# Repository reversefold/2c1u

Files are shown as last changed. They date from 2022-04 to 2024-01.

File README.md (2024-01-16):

# 2c1u - Two computers, one USB port

The name is a riff on 2p1c, a shorthand for "Two players, one controller", a fun challenge that some speedrunners enjoy.

This project has software and hardware designs which form a USB switch, allowing for automatically moving a USB device between two computers, either through pressing of a hardware button or controlled via software running on the computers. If you plug a USB hub into the port that is switched you can switch, for instance, a keyboard and mouse between two computers, as if you were using software like Synergy.

## Layout
* 2c1u_kicad - KiCAD files for the hardware of the project, including a PCB layout.
* CircuitPy_Adafruit - Software for the Raspberry Pi devices that the hardware uses.
* 2c1u, pyproject.toml, pdm.lock - These constitute the computer software which communicate to the hardware over USB-Serial.

## Hardware
Required hardware:
* 2x [Adafruit Feather RP2040](https://www.adafruit.com/product/4884)
* 2x [TinkerBoy USB 2.0 Hub Breakout](https://www.tinkerboy.xyz/product/tinkerboy-usb-hub-4-port-usb-hub-2-0/)
* 3x [Adafruit 4090 - USB-C Breakout](https://www.adafruit.com/product/4090)
* 2x [Omron G6SK-2-DC5 relays](https://www.mouser.com/ProductDetail/Omron-Electronics/G6SK-2-DC5?qs=Mrnyg3lK62HQss%2FMQAyqbw%3D%3D)
* 2x [PN2222A Transistor](https://www.digikey.com/en/products/detail/nte-electronics-inc/PN2222A/11655004)
* 2x [Tactile Button Switch](https://www.adafruit.com/product/367)
* 1x [Sparkfun Cherry MX Switch Breakout](https://www.sparkfun.com/products/13773)
* 1x Cherry MX Compatible Switch
* 1x Keycap
* 2x 1K resistors
* 2x 10K resistors

I am also using several feather breakout boards for additional output as I had them around to play with:
* 1x [NeoPixel FeatherWing](https://www.adafruit.com/product/2945)
* 1x [Adafruit FeatherWing OLED - 128x64](https://www.adafruit.com/product/4650)
* 1x [FeatherWing Tripler Mini Kit](https://www.adafruit.com/product/3417)

You will additionally need PCB mount headers for the various components and either breadboards or a custom PCB (see fully functional PCB in `2c1u_kicad`). Note that the TinkerBoy USB 2.0 Hub Breakout boards are not breadboard compatible, the holes are not uniformly separated and require some creativity to hook up with a breadboard.

All of the soldering for the PCB are through-hole, as are nearly all of the boards. The one exception is the two data pads on the RP2040 boards. These pads connect to the 2 data pins of the USB connector so they can be used to wire up the RP2040 to the TinkerBoy boards as a USB device.

The Raspberry Pi boards are the brains of the switch. Each one connects to one of the computers as a USB serial device as a control channel. The primary one also controls the relays which switch the USB devices between the two computers.

One USB connector is for the input device to switch between the two hosts. I use a simple USB hub and plug both my keyboard and mouse into it, then plug the hub into the switch. The other 2 USB connectors connect to the two host computers. The TinkerBoy boards act as USB hubs, allowing both the RPi boards and the input devices to be connected via one USB connection. Note that this switch supports USB 2.0 only, so it's only really useful for lower bandwidth devices, like HID devices.

The Cherry MX switch allows switching between the two host computers manually. The two small switch buttons next to the USB connectors on the PCB can be held down while plugging in the associated USB cable to have the RPi start up in developer mode, with a repl usb-serial connection and as usb mass storage.

## Device-side software
The device-side software is written in Python for CircuitPy running on an Adafruit device. For the secondary create a file named `secondary` in the root of the drive.

The `boot.py` file turns on the data interface and turns off the repl interface, as well as turns off the ability of the CircuitPy device to be a USB drive. If you want access to the USB drive and repl interface you can pull pin D5 up (the buttons next to the USB connectors on the PCB are for this).

## Computer-side software
The computer-side software is written in Python and uses pdm for dependency management. Once you've installed pdm, change to the project directory, use the command `pdm install` to have pdm install all of the dependencies, then use the command `pdm run python 2c1u/main.py` to start the software. Until you have the right hardware hooked up it will loop with exceptions about not finding the serial interface.

The code near the top that defines `X_EDGE` configures how the edge of the screen is detected for the two machines, one Windows on the right, and one not Windows on the left.

## History

This project is the culmination of years of thinking and tinkering in my free time. For a long time, I have used projects such as x2vnc and Synergy to have the mouse and keyboard of one computer move to another computer's screen over the network, allowing for easy use of multiple computers with their own screens with a single keyboard and mouse. When I started working from home more often I wanted a way to switch between my personal and work computers seamlessly. Synergy did just that for me for a while but there were always caveats. Slowdown on the computers and random network errors would cause the input to lag or disconnect.

When my work computer was forced to have a full tunnel VPN the fully software-based network solution just wouldn't work reliably any more. The classic solution to this was a KVM, a hardware switch meant to move a keyboard, video, and mouse from one computer to another. I had no need for the video part of this, however, and I had trouble finding anything which could be software controlled. I wanted to mimic what I could do with Synergy, moving my mouse to one side of the monitor and have my mouse and keyboard move seamlessly to the other computer's monitor next to it.

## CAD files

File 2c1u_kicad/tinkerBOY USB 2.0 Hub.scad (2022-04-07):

board_width = 21.86; // mm
board_width_px = 755;
board_height = 14.02; // mm
board_height_px = 476;
width_px_per_mm = board_width_px / board_width;
height_px_per_mm = board_height_px / board_height;

echo(width_px_per_mm=width_px_per_mm, height_px_per_mm=height_px_per_mm);

pad_width_px = 64;
hole_width_px = 32;
pad_width = pad_width_px / width_px_per_mm;
hole_width = hole_width_px / width_px_per_mm;

echo(pad_width=pad_width, hole_width=hole_width);

left_to_center_of_first_pad_px = 47;
left_pad_x = left_to_center_of_first_pad_px / width_px_per_mm;
bottom_to_center_of_pad_px = 39;
pad_y = bottom_to_center_of_pad_px / width_px_per_mm;
echo(left_pad_x=left_pad_x);

pad_group_center_dist_px = 89;
pad_group_center_dist = pad_group_center_dist_px / width_px_per_mm;
echo(pad_group_center_dist=pad_group_center_dist);
pad_group_padding_px = 102;
pad_group_padding = pad_group_padding_px / width_px_per_mm;
echo(pad_group_padding=pad_group_padding);

$fn = 30;

echo(79 / width_px_per_mm);
echo(169 / width_px_per_mm);

difference() {
    square(size=[board_width, board_height]);

    for(i = [0 : 1 : 7]) {
        echo(i=i, pad_x=pad_x);
        pad_x = left_pad_x + floor(i / 2) * (pad_group_center_dist + pad_group_padding) + (i % 2) * pad_group_center_dist;
        translate([pad_x, pad_y, 0]) {
            cylinder(h=2, r=pad_width / 2, center=true);
        }
    }
}
/*
343.55 px / cm

hole width 36px = 0.10479 cm
pad width 64px = 1.8629 cm
dist from left to center 47px = 0.166 cm
bottom to center 39px = 0.163 cm

dist between first centers 89px = 0.259 cm

pad size 2.1121
hole size 1.0479

103px = 0.2998cm
*/

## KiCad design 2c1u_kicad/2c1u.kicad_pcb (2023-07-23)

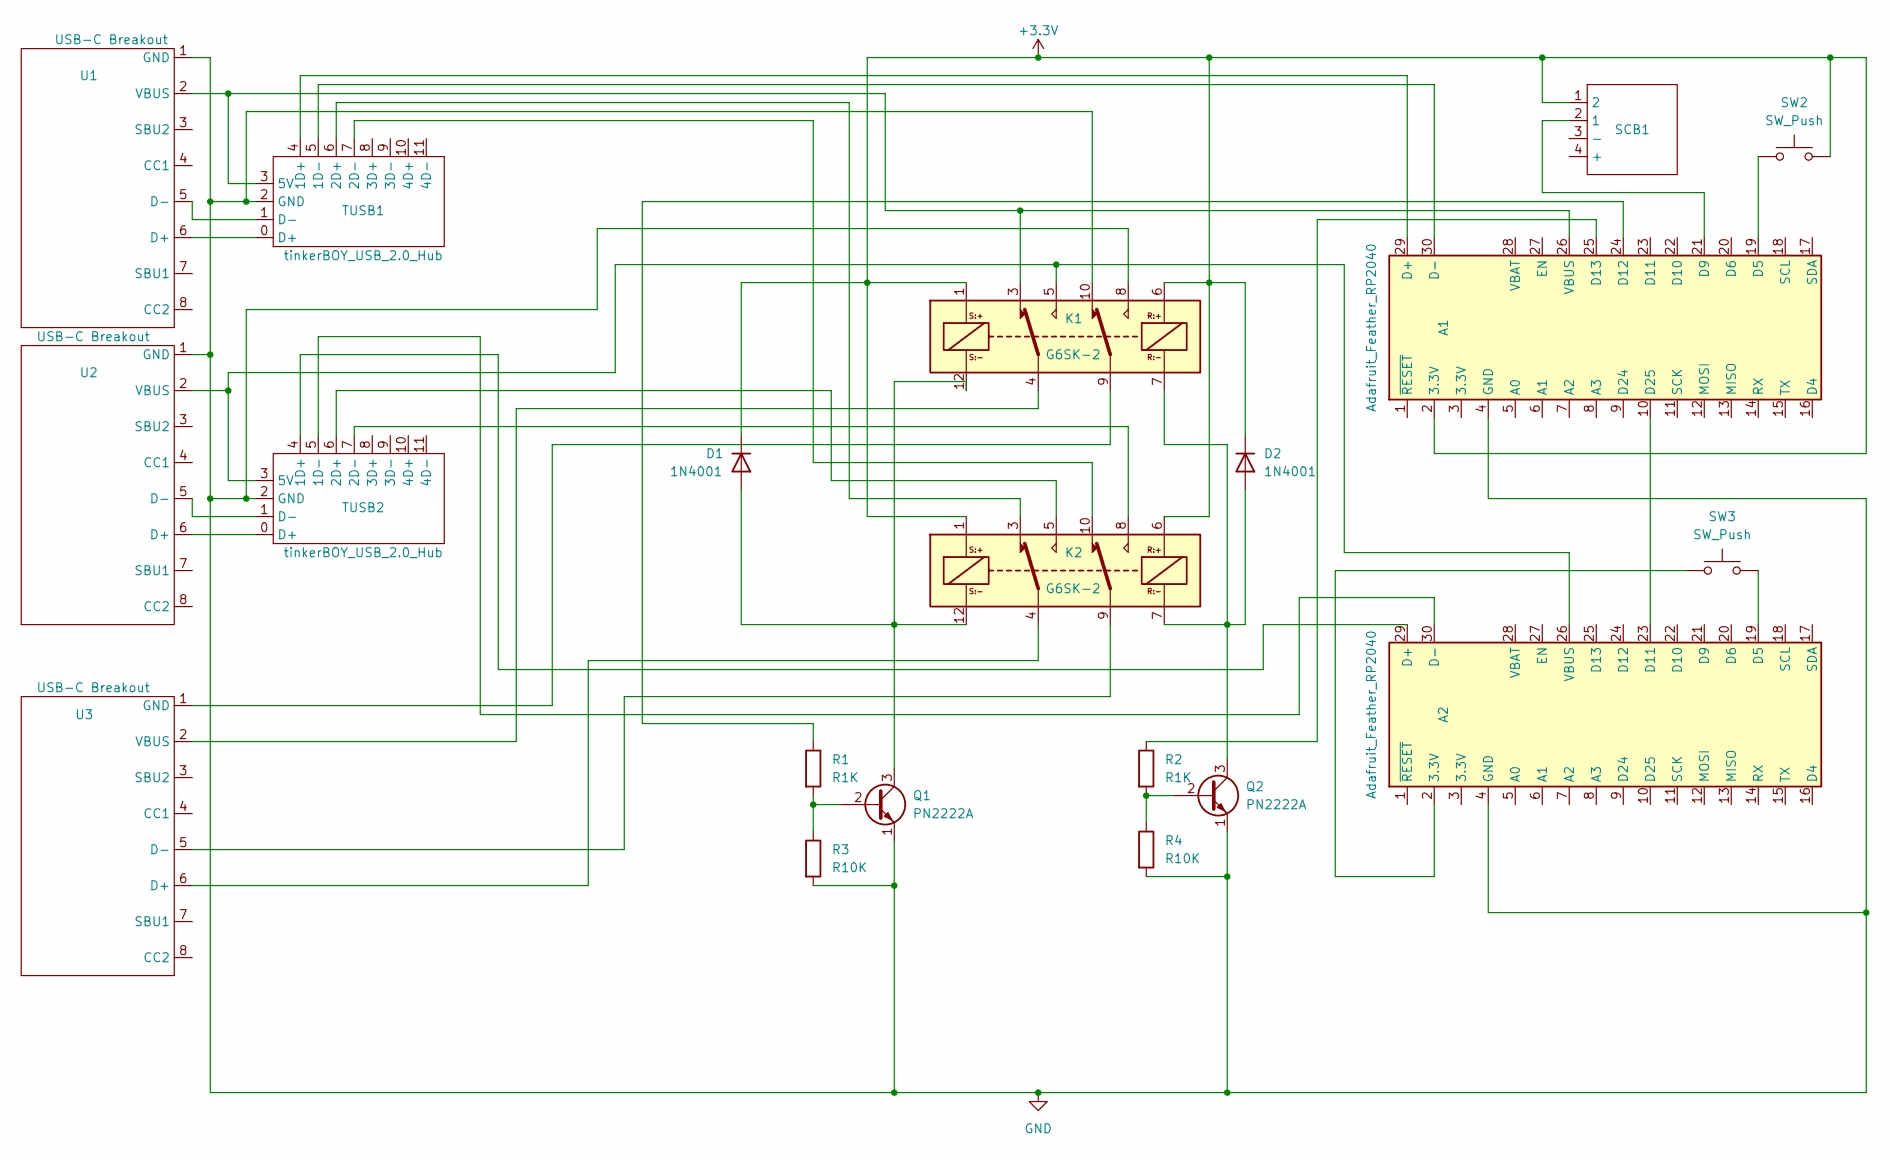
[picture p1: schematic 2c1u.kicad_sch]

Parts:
A1, A2: Adafruit_Feather_RP2040; Adafruit Feather RP2040
D1, D2: 1N4001; D_DO-41_SOD81_P10.16mm_Horizontal
K1, K2: G6SK-2; Relay_DPDT_Omron_G6SK-2
Q1, Q2: PN2222A; TO-92_Inline
R1, R2: R1K; R_Axial_DIN0204_L3.6mm_D1.6mm_P5.08mm_Horizontal
R3, R4: R10K; R_Axial_DIN0204_L3.6mm_D1.6mm_P5.08mm_Horizontal
SCB1: (no value)
SW2, SW3: SW_Push; SW_Tactile_Straight_KSL0Axx1LFTR
TUSB1, TUSB2: tinkerBOY_USB_2.0_Hub; tinkerBOY USB 2.0 Hub
U1, U2, U3: USB-C Breakout; Adafruit 4090 - USB-C Breakout

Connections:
+3V3: A1.2 (3.3V), D1.1 (K), D2.1 (K), K1.1, K1.6, K2.1, K2.6, SCB1.1 (2), SW2.2
GND: A1.4 (GND), A2.4 (GND), K1.8, K1.10, Q1.1 (E), Q2.1 (E), R3.2, R4.2, TUSB1.2 (GND), TUSB2.2 (GND), U1.1 (GND), U2.1 (GND)
unnamed: A1.10 (D25), A2.23 (D11)
unnamed: A1.19 (D5), SW2.1
unnamed: A1.24 (D12), R1.1
unnamed: A1.25 (D13), R2.1
unnamed: A1.26 (VBUS), K1.3, TUSB1.3 (5V), U1.2 (VBUS)
unnamed: A1.29 (D+), TUSB1.4 (1D+)
unnamed: A1.30 (D-), TUSB1.5 (1D-)
unnamed: A2.2 (3.3V), SW3.1
unnamed: A2.19 (D5), SW3.2
unnamed: A2.26 (VBUS), K1.5, TUSB2.3 (5V), U2.2 (VBUS)
unnamed: A2.29 (D+), TUSB2.4 (1D+)
unnamed: A2.30 (D-), TUSB2.5 (1D-)
unnamed: D1.2 (A), K1.12, K2.12, Q1.3 (C)
unnamed: D2.2 (A), K1.7, K2.7, Q2.3 (C)
unnamed: K1.4, U3.2 (VBUS)
unnamed: K1.9, U3.1 (GND)
unnamed: K2.3, TUSB1.6 (2D+)
unnamed: K2.4, U3.6 (D+)
unnamed: K2.5, TUSB2.6 (2D+)
unnamed: K2.8, TUSB2.7 (2D-)
unnamed: K2.9, U3.5 (D-)
unnamed: K2.10, TUSB1.7 (2D-)
unnamed: Q1.2 (B), R1.2, R3.1
unnamed: Q2.2 (B), R2.2, R4.1
unnamed: A1.21 (D9), SCB1.2 (1)
unnamed: TUSB1.0 (D+), U1.6 (D+)
unnamed: TUSB1.1 (D-), U1.5 (D-)
unnamed: TUSB2.0 (D+), U2.6 (D+)
unnamed: TUSB2.1 (D-), U2.5 (D-)

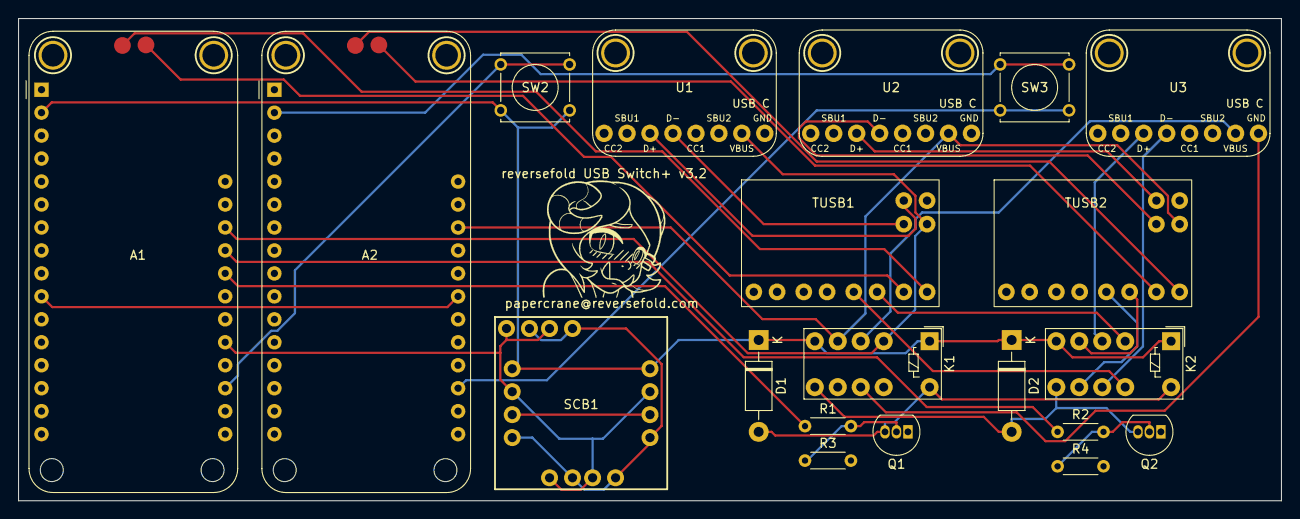
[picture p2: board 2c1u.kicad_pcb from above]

Board: 2 copper layers, 139.7 x 53.3 mm, 20 parts (0 on the bottom side), 31 nets.

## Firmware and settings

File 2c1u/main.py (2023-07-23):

import asyncio
import datetime
import glob
import logging
import sys

import adafruit_board_toolkit.circuitpython_serial
import serial_asyncio
import serial.serialutil
import pyautogui


logging.basicConfig(level=logging.INFO)
LOG = logging.getLogger(__name__)

zero_time_threshold = datetime.timedelta(seconds=0.2)
ser_write = None

loop = asyncio.new_event_loop()


class Operator(object):
    @staticmethod
    def apply(a, b):
        raise Unimplemented()


class GreaterThan(Operator):
    @staticmethod
    def apply(a, b):
        return a > b


class LessThan(Operator):
    @staticmethod
    def apply(a, b):
        return a < b


EDGE_THRESHOLD = 5
MAX_DIFF = 300
if sys.platform.startswith("win"):
    X_EDGE = 0 + EDGE_THRESHOLD
    OPERATOR = LessThan
else:
    X_EDGE = 2559 - EDGE_THRESHOLD
    OPERATOR = GreaterThan


ser_read = ser_write = None


async def serial_write():
    global ser_read, ser_write

    while True:
        while not ser_write:
            LOG.info("Waiting for serial write connection")
            await asyncio.sleep(1)

        try:
            command = b"hello\n\r"
            print(f"<<[{command}]")

            ser_write.write(command)  # write a string
            await ser_write.drain()
            print("written")

            # for _ in range(len(command)):
            #    a = await ser_read.read()  # Read the loopback chars and ignore
            # print("read echo")

            # reply = b""
            # while True:
            #     a = await ser_read.read(1)
            #     if a == b"\r":
            #         print(f">>[{reply}]")
            #         reply = b""
            #     else:
            #         reply += a
            #     await asyncio.sleep(0.1)
        except Exception:
            LOG.exception("Exception in serial_write loop, retrying in 1s")
            await asyncio.sleep(1)


async def open_serial():
    global ser_read, ser_write
    if ser_read:
        try:
            await ser_read.close()
        except Exception:
            LOG.exception("Exception closing serial read")
    if ser_write:
        try:
            await ser_write.close()
        except Exception:
            LOG.exception("Exception closing serial write")
    ports = adafruit_board_toolkit.circuitpython_serial.data_comports()
    if not ports:
        raise Exception("No adafruit board serial data connections found")
    serial_device = ports[0].device
    LOG.info("Connecting to serial device %s" % (serial_device,))
    ser_read, ser_write = await serial_asyncio.open_serial_connection(
        url=serial_device,
        baudrate=115200,
        loop=loop,
    )


async def serial_read():
    global ser_read, ser_write

    while True:
        # import ipdb; ipdb.set_trace()
        try:
            await open_serial()

            while not ser_read:
                LOG.info("Waiting for serial read connection")
                await asyncio.sleep(1)

            # command = b"hello\n\r"
            # print(f"<<[{command}]")

            # ser_write.write(command)  # write a string
            # await ser_write.drain()
            # print("written")

            # for _ in range(len(command)):
            #    a = await ser_read.read()  # Read the loopback chars and ignore
            # print("read echo")

            reply = b""
            while True:
                a = await ser_read.read(1)
                if a == b"\r":
                    print(f">>[{reply}]")
                    reply = b""
                else:
                    reply += a
                await asyncio.sleep(0.1)
        except Exception:
            LOG.exception("Exception in serial_read loop, retrying in 1s")
            await asyncio.sleep(1)
        finally:
            try:
                await ser_read.close()
            except Exception:
                LOG.exception("Exception closing serial read")
            try:
                await ser_write.close()
            except Exception:
                LOG.exception("Exception closing serial write")
            ser_read = ser_write = None


async def cursor_watch():
    while not ser_write:
        await asyncio.sleep(1)

    while True:
        try:
            last_pos_x = pyautogui.size()[0] / 2
            edge_start = None
            switched = False
            while True:
                await asyncio.sleep(0.1)
                pos_x, _ = pyautogui.position()
                if pos_x == last_pos_x and edge_start is None:
                    continue
                if pos_x != last_pos_x:
                    print(pos_x)
                diff = abs(last_pos_x - X_EDGE)
                if OPERATOR.apply(pos_x, X_EDGE) and (
                    edge_start is not None or diff < MAX_DIFF
                ):
                    if edge_start is None:
                        print(diff)
                        print("edge_start")
                        edge_start = datetime.datetime.now()
                    if datetime.datetime.now() - edge_start > zero_time_threshold:
                        if not switched:
                            print("switch")
                            switched = True
                            command = b"switch\n\r"
                            ser_write.write(command)
                            await ser_write.drain()
                            print(f"<<[{command}]")
                else:
                    edge_start = None
                    if switched:
                        print("Switch off")
                        switched = False
                last_pos_x = pos_x
        except serial.serialutil.SerialException:
            await open_serial()
        except Exception:
            LOG.exception("Exception in cursor_watch loop, retrying in 1s")
            await asyncio.sleep(0.1)


# loop.create_task(serial_write())
loop.create_task(serial_read())
loop.create_task(cursor_watch())
loop.run_forever()
loop.close()

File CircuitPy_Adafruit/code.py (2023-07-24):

import os
import time

import board
import digitalio
import neopixel
import supervisor
import usb_cdc


print("listening...")

RED = (255, 0, 0)
# YELLOW = (255, 150, 0)
# GREEN = (0, 255, 0)
# CYAN = (0, 255, 255)
BLUE = (0, 0, 255)
PURPLE = (180, 0, 255)
# WHITE = (255, 255, 255)
# OFF = (0, 0, 0)

try:
    os.stat("secondary")
    SECONDARY = True
    print("secondary")
except OSError:
    SECONDARY = False

PRIMARY = not SECONDARY


if PRIMARY:
    button = digitalio.DigitalInOut(board.D9)
    button.switch_to_input(pull=digitalio.Pull.DOWN)


if PRIMARY:
    pixels = neopixel.NeoPixel(board.D6, 8 * 4, brightness=0.05, auto_write=False)
    pixel = neopixel.NeoPixel(board.NEOPIXEL, 1, brightness=0.05, auto_write=False)
else:
    pixels = neopixel.NeoPixel(board.NEOPIXEL, 1, brightness=0.05, auto_write=False)

switch_to_0_out = digitalio.DigitalInOut(board.D13)
switch_to_0_out.switch_to_output()
switch_to_1_out = digitalio.DigitalInOut(board.D12)
switch_to_1_out.switch_to_output()

switch = digitalio.DigitalInOut(board.D4 if PRIMARY else board.D11)
switch.switch_to_output()

switch_in = digitalio.DigitalInOut(board.D25)
switch_in.switch_to_input(pull=digitalio.Pull.DOWN)

# output_enable = digitalio.DigitalInOut(board.A2)
# output_enable.switch_to_output()


if PRIMARY:
    try:
        import adafruit_displayio_sh1107

        # import adafruit_displayio_ssd1306
        import adafruit_display_text.label
        import displayio
        import terminalio

        displayio.release_displays()
        i2c = board.I2C()
        display_bus = displayio.I2CDisplay(i2c, device_address=0x3C)
        # display = adafruit_displayio_ssd1306.SSD1306(display_bus, width=128, height=32)
        display = adafruit_displayio_sh1107.SH1107(display_bus, width=128, height=64)
    except RuntimeError as exc:
        print("Error initializing display: %r" % (exc,))
        display = None


def update_display(text):
    if not display:
        return
    # Make the display context
    splash = displayio.Group()
    display.show(splash)

    color_bitmap = displayio.Bitmap(128, 32, 1)
    color_palette = displayio.Palette(1)
    color_palette[0] = 0xFFFFFF  # White

    bg_sprite = displayio.TileGrid(color_bitmap, pixel_shader=color_palette, x=0, y=0)
    splash.append(bg_sprite)

    # Draw a smaller inner rectangle
    inner_bitmap = displayio.Bitmap(118, 24, 1)
    inner_palette = displayio.Palette(1)
    inner_palette[0] = 0x000000  # Black
    inner_sprite = displayio.TileGrid(
        inner_bitmap, pixel_shader=inner_palette, x=5, y=4
    )
    splash.append(inner_sprite)

    # Draw a label
    text_area = adafruit_display_text.label.Label(
        terminalio.FONT,
        text=text,
        color=0xFFFF00,
        x=int(128 / 2 - len(text) / 2 * 6),
        y=15,
    )
    splash.append(text_area)


def _wheel(pos):
    # Input a value 0 to 255 to get a color value.
    # The colours are a transition r - g - b - back to r.
    if pos < 0 or pos > 255:
        return (0, 0, 0)
    if pos < 85:
        return (255 - pos * 3, pos * 3, 0, 0)
    if pos < 170:
        pos -= 85
        return (0, 255 - pos * 3, pos * 3, 0)
    pos -= 170
    return (pos * 3, 0, 255 - pos * 3, 0)


def wheel(pos):
    col = _wheel(pos)
    return tuple(int(c / 10) for c in col)


last_out = 0
timer = 0
PERIOD = 100
COLOR_RATIO = 0.5


def mix_colors(color1, color2):
    color = tuple(
        color1[i] * COLOR_RATIO + color2[i] * (1 - COLOR_RATIO) for i in (0, 1, 2)
    )
    return color


def update_pixels(color):
    global last_out, timer

    # t = float(timer if timer < PERIOD / 2 else PERIOD - timer)  # PERIOD / 2 - (timer - PERIOD / 2))
    # pixels.brightness = t / (PERIOD / 2) * 0.04 + 0.01
    # m = 1 # (t / (PERIOD / 2)) / 2.0 + 0.5
    # color = tuple(int(v * m) for v in color)

    # ts = time.time()
    # if ts != last_out:
    #     print(">", ts, color)
    #     last_out = ts
    # pixels.fill(color)  #  * int(ts % 5 / 5.0)
    for x in range(len(pixels) // 4):
        # col = tuple(int(v * (((x + 7.0 * timer / PERIOD) % 7.0) / 7.0 * 0.5 + 0.5)) for v in color)
        for y in range(len(pixels) // 8):
            rainbow_color = _wheel(
                (
                    (x + y) * 255.0 / 16
                    + (1 if switch.value else -1) * timer * 255.0 / PERIOD
                )
                % 256
            )
            col = mix_colors(color, rainbow_color)
            if (
                not switch.value
                and (y == 3 or (x, y) in ((6, 2), (5, 1), (4, 0)))
                or switch.value
                and (y == 0 or (x, y) in ((1, 1), (2, 2), (3, 3)))
            ):
                col = tuple(c // 6 for c in color)  # mix_colors(rainbow_color, col)
            pixels[y * 8 + x] = col
    # pixels[0] = (255,0,0)
    # pixels[1] = (0,255,0)
    pixels.show()
    if PRIMARY:
        pixel[0] = pixels[0]
        pixel.show()

    timer = (timer + 1) % PERIOD


if PRIMARY:
    update_display("primary")
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

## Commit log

2022-04-06 Use the data serial device rather than the repl serial device Default to turning off the storage and repl devices with an option to turn them on if a button is held Use adafruit_board_toolkit to find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
2022-04-06 Add KiCAD and gerber files for rev 1.0
    [rfkvm-B_Cu.gbl, rfkvm-B_Mask.gbs, rfkvm-B_Paste.gbp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]
2022-04-07 Various updates and fixes * Only GND plane, no 3.3v plane, reduces complexity * Added text for version * Added graphics for fun * Fixed some alignments * Might have fixed some unconnected pads
    [rfkvm-B_Cu.gbl, rfkvm-B_Mask.gbs, rfkvm-B_Paste.gbp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]
2022-04-22 Switch to latching relays which allow us to apply current momentarily to switch the relay instead of keeping the current always flowing for one side of the relay
2023-07-23 rfkvm -> 2c1u
    [2c1u-B_Cu.gbl, 2c1u-B_Mask.gbs, 2c1u-B_Paste.gbp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]
2023-07-24 Add a BOM with links and a description of the hardware and software
